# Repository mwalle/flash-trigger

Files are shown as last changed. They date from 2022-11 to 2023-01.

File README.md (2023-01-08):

# Tiny LED Trigger

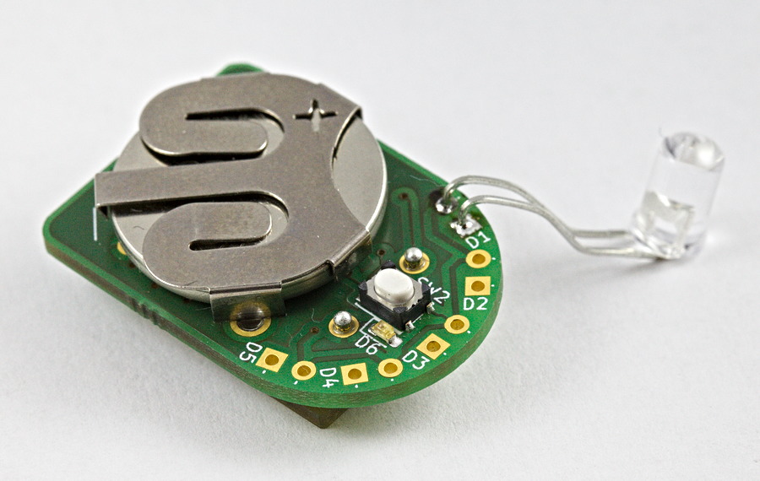
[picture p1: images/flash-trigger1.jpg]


Your simple, cheap and open LED flash trigger for your underwater strobe.

## Features



The flash trigger provides the following features:

- Reliably triggers your optical underwater strobe in manual mode.
- Converts any trigger pulse from your camera to a constant 100µs LED
  pulse.
- Very bright pulse because the LED is driven with a very high current
  (most LEDs have a peak forward current of 100mA-150mA specified for
  100µs for a 1/10 duty cycle).
- Pre-flash supression mode. Useful if your camera has a pre-flash pulse on
  the hot shoe pin.
- Powered by just one CR2032 coin cell.
- More than 10.000 cycles per coin cell.
- Five different positions for the LED.
- Supports up to two LEDs in parallel.
- Battery good indication.
- Extremely small.
- [Open Hardware](https://certification.oshwa.org/de000130.html),
  schematics and layout are free for everyone.

## Pictures

<p>
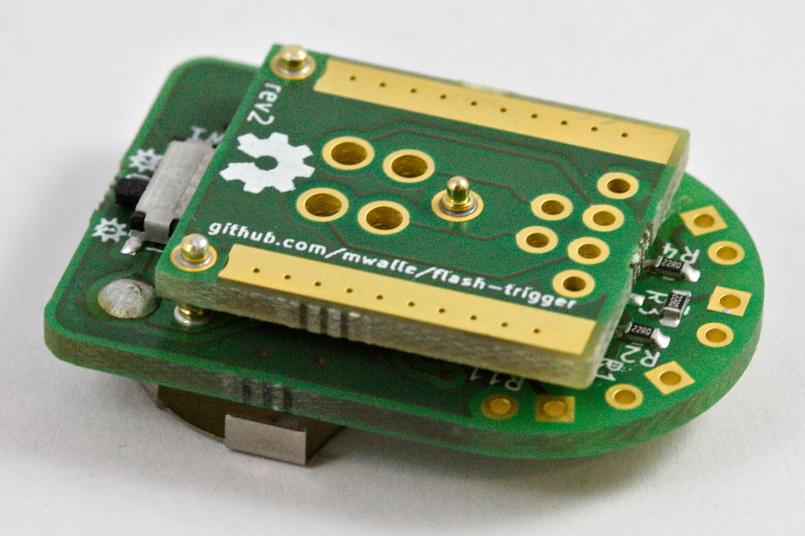
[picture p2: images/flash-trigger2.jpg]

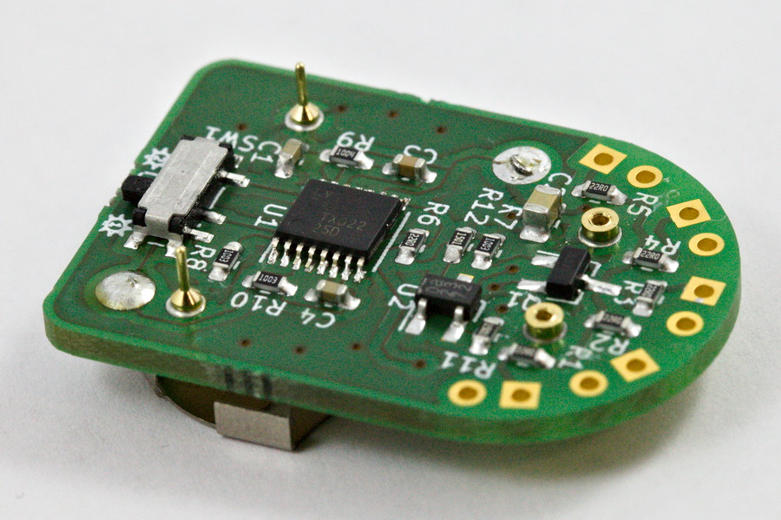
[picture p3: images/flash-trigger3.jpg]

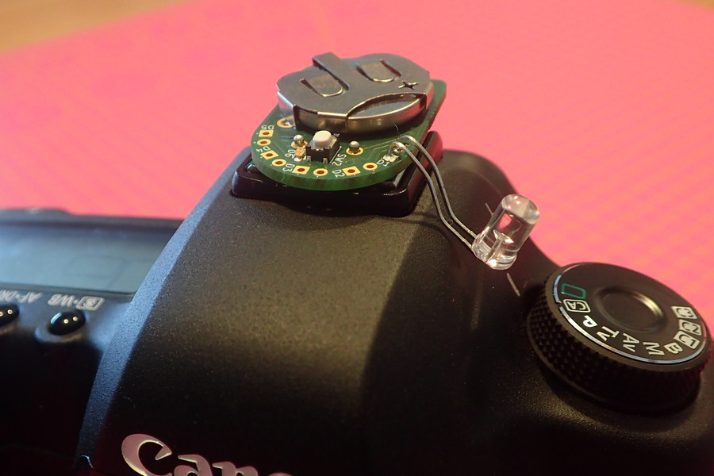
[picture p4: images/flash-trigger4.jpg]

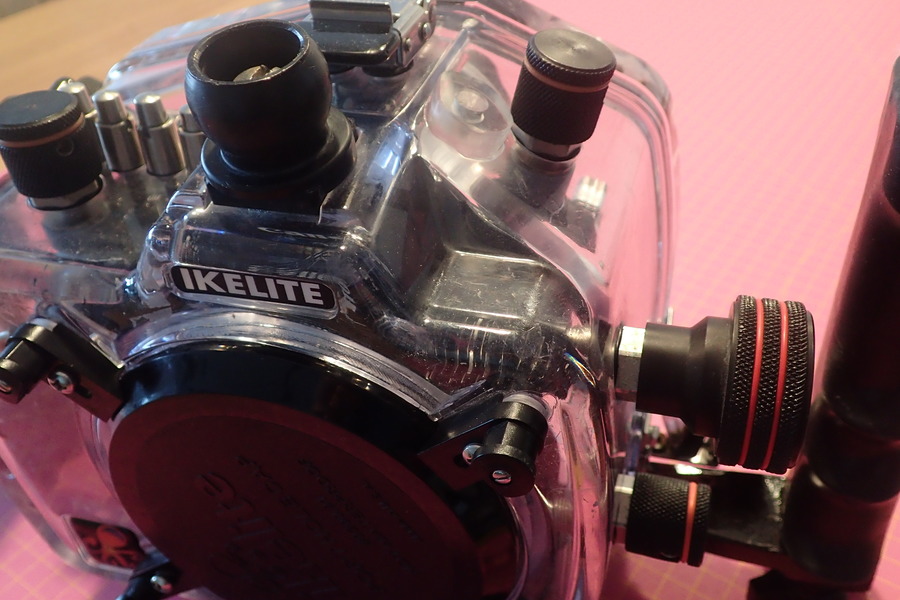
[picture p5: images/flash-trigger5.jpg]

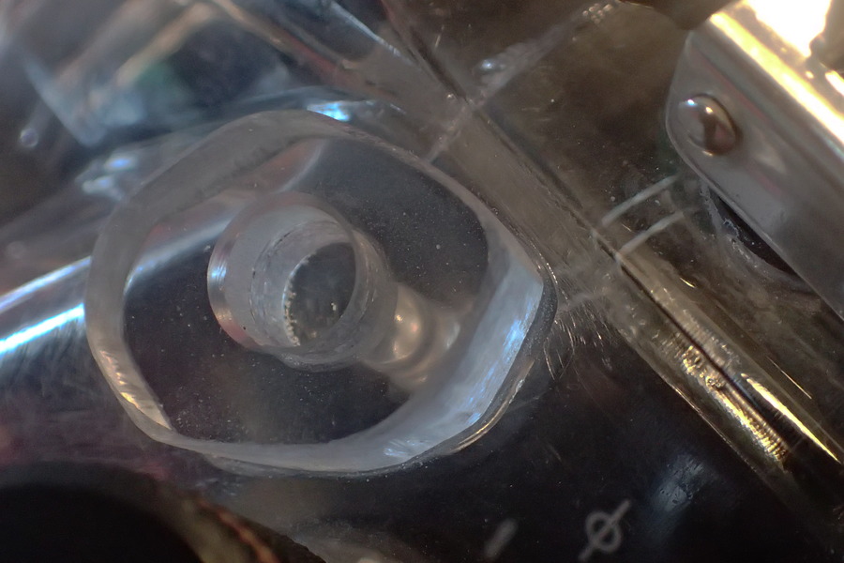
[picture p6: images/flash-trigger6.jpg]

</p>

## Schematics
The LED trigger consists of:
 - the [base board](flash-trigger/flash-trigger.pdf) and
 - a [Canon compatible hot shoe](canon-hotshoe/canon-hotshoe.pdf).

Only populate the X pin of the hot shoe to be compatible with any camera.

## Theory Of Operation

At the heart of the circuit, there is a monostable multivibrator (`U1B`)
which converts any falling edge of the trigger output of your camera to a
constant length pulse of about 100µs. The time constant is given by the
values of `C1` and `R3`. The multivibrator is retriggerable, thus if there
would be a second falling edge within that 100µs pulse the period would
start over. But in practice, this shouldn't matter.

A second monostable multivibrator (`U1A`) can be used to supress a
pre-flash pulse. In this case, the second input of `U1B` is connected to
the output of `U1A` and only if that output is active the 100µs pulse is
generated. The output of `U1A` in turn, will be active for about 100ms
after a *rising* edge of the flash trigger input. Thus the sequence is as
follows:
 1. The camera pulses the trigger output low to generate a pre-flash.
 2. Normally, `U1B` would now trigger a pulse on the falling edge, but
	because the second input is still inactive, no pulse is generated.
 3. On the rising edge (that is, at the end of the pre-flash pulse), `U1A`
	triggers a 100ms pulse and arm `U1B`.
 4. The camera triggers the actual main flash by pulsing the output trigger
	again.
 5. This time, the second input of `U1B` is active and the 100µs trigger
	pulse will be generated.

This has the following two implications:
 * The duration between pre-flash and the main flash must not exceed 100ms.
 * Repeated flashes will be limited to about 10Hz (reciprocal value of the
   100ms)

Both shouldn't really matter. But of course you can tune this time constant
by changing the values of `C3` and `R9`.

The 100µs pulse is enabling the logic level N-channel MOSFET `Q1`, which is
driving the LEDs `D1`..`D5` through individual series resistors `R1`..`R5`.
Depending on the value of the series resistor and the LEDs, it should be
possible to connect up to two LEDs.

The circuit is designed to work down to the forward voltage of the LED.
`U1` will work down to 1.0V. Nevertheless, there is a voltage supervisor,
which is pretty simple: `U2` will pull its output to high if its supply
voltage is greater than 2.7V, thus driving the green LED `D6` with its
series resistor `R11`. At 2.7V the coin cell should still have about 25% of
its capacity, giving the user enough margin.

## Trigger LEDs

The flash trigger has five different LED positions facing left to right.
It should be possible to populate up to two LEDs. The LEDs should be chosen
according to the flash you like to use. The author has successfully tried
red and infrared LEDs with INON flashes. The more the LED is towards the
infrared spectrum, the lower is its forward voltage and the longer it will
work with a given coin cell.

## Bill Of Materials

| Ref | Qty | Part | Footprint |
| --- | --- | --- | --- |
| R1, R2, R3, R4, R5, R6 | 6 | 10Ω Resistor | 0603 |
| R7, R8, R10 | 3 | 100kΩ Resistor | 0603 |
| R9 | 1 | 1MΩ Resistor | 0603 |
| R11, R12 | 2 | 1.5kΩ Resistor | 0603 |
| C1 | 1 | 10nF Ceramic Capacitor | 0603 |
| C2 | 1 | 100µF Ceramic Capacitor | 0805 |
| C3 | 1 | 200nF Ceramic Capacitor | 0603 |
| C4 | 1 | 2.2nF Ceramic Capacitor | 0603 |
| C5 | 1 | 100pF Ceramic Capacitor | 0603 |
| D1, D2, D3, D4, D5 | 5 | LED | THT |
| D6 | 1 | Green LED | 0603 |
| Q1 | 1 | NDS331N N-Channel MOSFET | SOT23-3 |
| U1 | 1 | 74LV123 Dual Retriggerable Monostable Multivibrator | SSOP16 |
| U2 | 1 | BD49K27G Voltage Supervisor 2.7V | SSOP3 |
| SW1 | 1 | PCM12 Switch | - |
| SW2 | 1 | PTS810 Push Button | - |
| BT1 | 1 | CR2032 Coin Cell Holder | - |
| J1, J2 | 2 | MillMax 0550 Pin Receptable | - |
| J3, J4 | 2 | MillMax 0508 PCB Pin | - |

## Kits and PCBs

If you need a PCB, a kit or maybe an assembled board, contact me at
<flash-trigger@walle.cc>.

## License

This source describes Open Hardware and is licensed under the CERN-OHL-S
v2.

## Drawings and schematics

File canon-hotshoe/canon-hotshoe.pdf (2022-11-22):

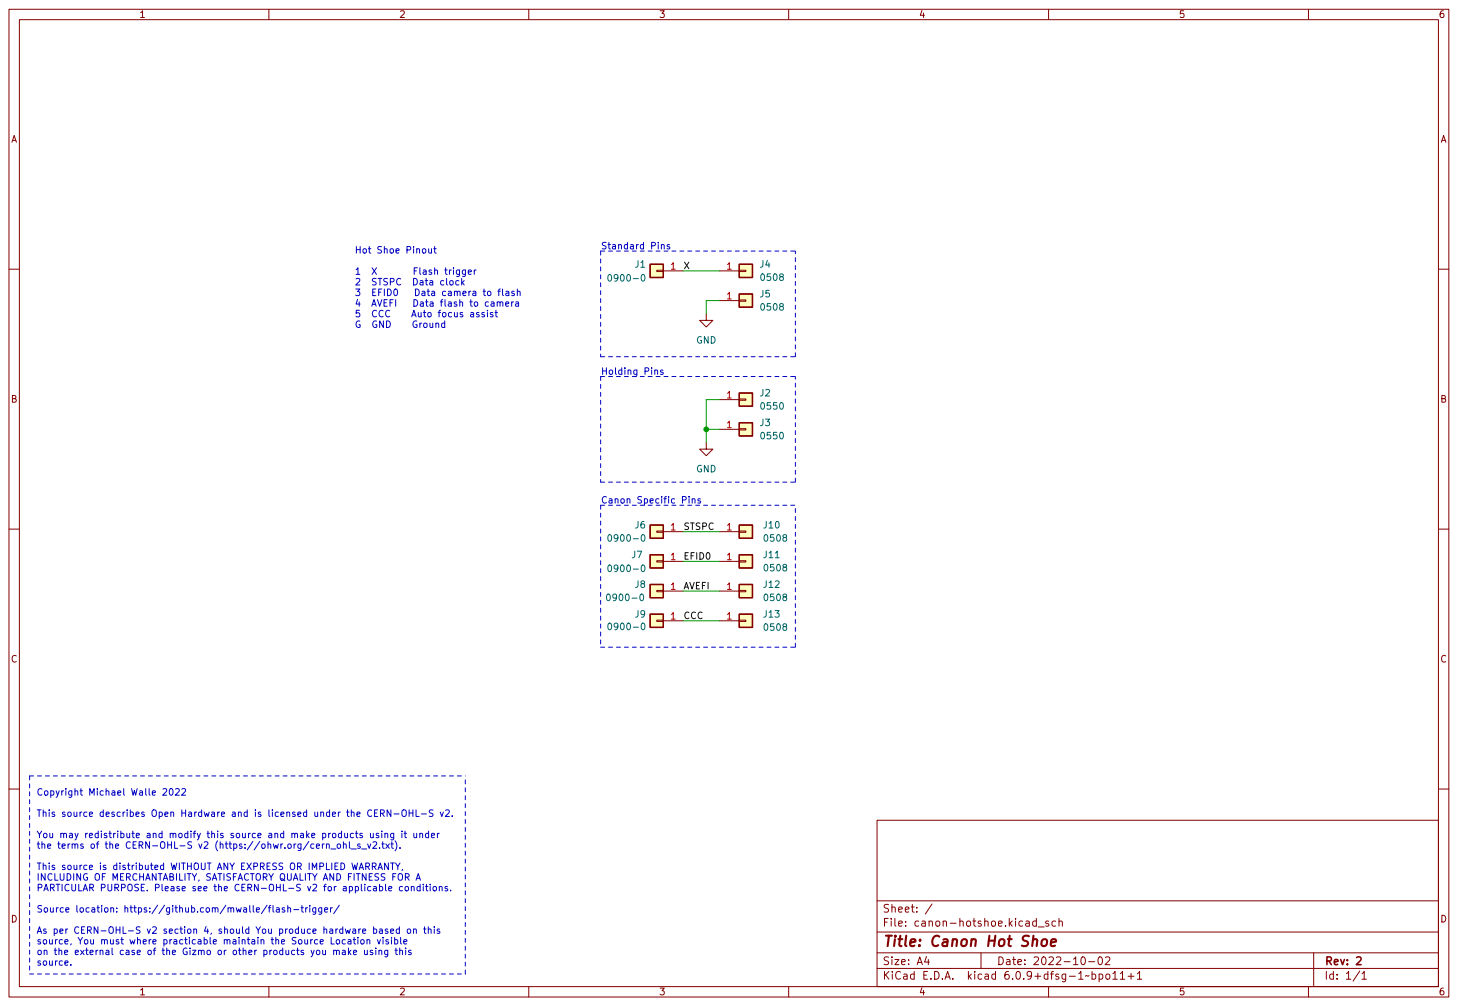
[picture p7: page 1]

4 AVEFI Data flash to camera

This source describes Open Hardware and is licensed under the CERN-OHL-S v2.

You may redistribute and modify this source and make products using it under
the terms of the CERN-OHL-S v2 (https://ohwr.org/cern_ohl_s_v2.txt). This source is distributed WITHOUT ANY EXPRESS OR IMPLIED WARRANTY,

INCLUDING OF MERCHANTABILITY, SATISFACTORY QUALITY AND FITNESS FOR A
PARTICULAR PURPOSE. Please see the CERN-OHL-S v2 for applicable conditions.

File: canon-hotshoe.kicad_sch Sheet: /
Id: 1/1 Title: Canon Hot Shoe

Source location: https://github.com/mwalle/flash-trigger/
As per CERN-OHL-S v2 section 4, should You produce hardware based on this
source, You must where practicable maintain the Source Location visible
on the external case of the Gizmo or other products you make using this
source.

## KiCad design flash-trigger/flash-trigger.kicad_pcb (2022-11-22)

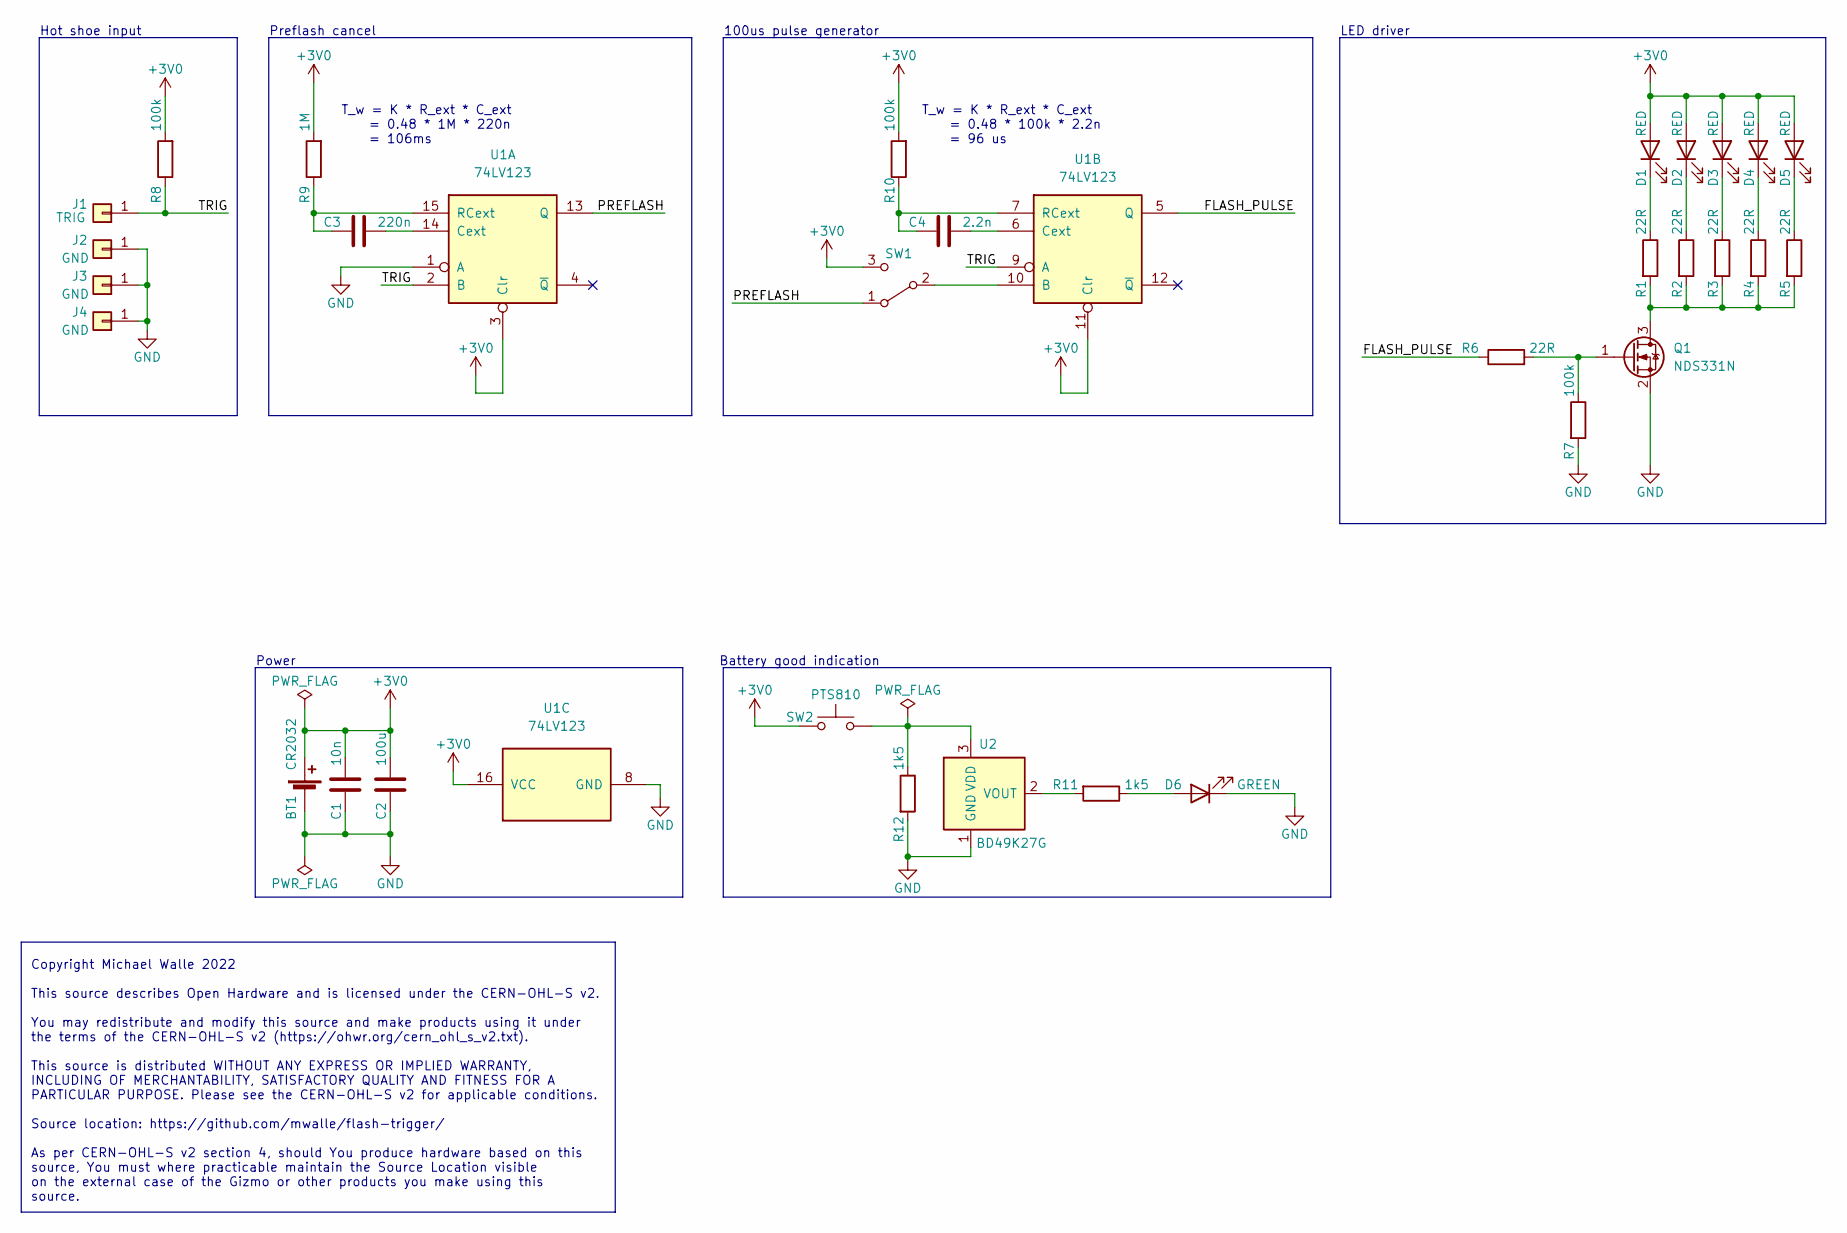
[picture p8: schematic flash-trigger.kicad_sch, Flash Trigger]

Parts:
BT1: CR2032; BatteryHolder_Keystone_2899_1x2032
C1: 10n; C_0603_1608Metric_Pad1.08x0.95mm_HandSolder
C2: 100u; C_0805_2012Metric_Pad1.18x1.45mm_HandSolder
C3: 220n; C_0603_1608Metric_Pad1.08x0.95mm_HandSolder
C4: 2.2n; C_0603_1608Metric_Pad1.08x0.95mm_HandSolder
D1, D2, D3, D4, D5: RED; LED_D5.0mm_Horizontal_O3.81mm_Z3.0mm
D6: GREEN; LED_0603_1608Metric_Pad1.05x0.95mm_HandSolder
J1: TRIG; 0550_52mil
J2: GND; 0550_52mil
J3, J4: GND; 0508_20mil
Q1: NDS331N; SOT-23_Handsoldering
R1, R2, R3, R4, R5, R6: 22R; R_0603_1608Metric_Pad0.98x0.95mm_HandSolder
R7, R8, R10: 100k; R_0603_1608Metric_Pad0.98x0.95mm_HandSolder
R9: 1M; R_0603_1608Metric_Pad0.98x0.95mm_HandSolder
R11, R12: 1k5; R_0603_1608Metric_Pad0.98x0.95mm_HandSolder
SW1: PCM12; SW_SPDT_PCM12
SW2: PTS810; SW_SPST_PTS810
U1: 74LV123; SSOP-16_4.4x5.2mm_P0.65mm
U2: BD49K27G; SOT-23_Handsoldering

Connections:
+3V0: BT1.1 (+), C1.1, C2.1, D1.2 (A), D2.2 (A), D3.2 (A), D4.2 (A), D5.2 (A), R8.2, R9.2, R10.2, SW1.3 (C), SW2.1, U1.3 (Clr), U1.11 (Clr), U1.16 (VCC)
/FLASH_PULSE: R6.1, U1.5 (Q)
/PREFLASH: SW1.1 (A), U1.13 (Q)
/TRIG: J1.1, R8.1, U1.2 (B), U1.9 (A)
GND: BT1.2 (-), C1.2, C2.2, D6.1 (K), J2.1, J3.1, J4.1, Q1.2 (S), R7.2, R12.2, U1.1 (A), U1.8 (GND), U2.1 (GND)
unnamed: C3.1, U1.14 (Cext)
unnamed: C3.2, R9.1, U1.15 (RCext)
unnamed: C4.1, U1.6 (Cext)
unnamed: C4.2, R10.1, U1.7 (RCext)
unnamed: D1.1 (K), R1.1
unnamed: D2.1 (K), R2.1
unnamed: D3.1 (K), R3.1
unnamed: D4.1 (K), R4.1
unnamed: D5.1 (K), R5.1
unnamed: D6.2 (A), R11.1
unnamed: Q1.1 (G), R6.2, R7.1
unnamed: Q1.3 (D), R1.2, R2.2, R3.2, R4.2, R5.2
unnamed: R11.2, U2.2 (VOUT)
unnamed: R12.1, SW2.2, U2.3 (VDD)
unnamed: SW1.2 (B), U1.10 (B)

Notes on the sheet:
100us pulse generator
Battery good indication
T_w = K * R_ext * C_ext = 0.48 * 100k * 2.2n = 96 us
Power
Copyright Michael Walle 2022 This source describes Open Hardware and is licensed under the CERN-OHL-S v2. You may redistribute and modify this source and make products using it under the terms of the CERN-OHL-S v2 (https://ohwr.org/cern_ohl_s_v2.txt). This source is distributed WITHOUT ANY EXPRESS 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
Hot shoe input
LED driver
T_w = K * R_ext * C_ext = 0.48 * 1M * 220n = 106ms
Preflash cancel

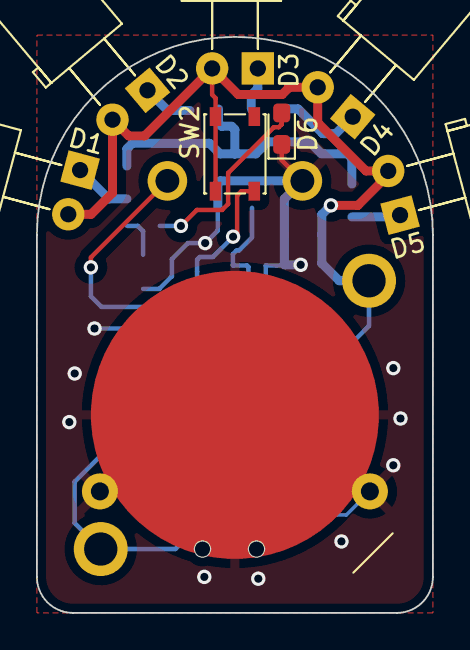
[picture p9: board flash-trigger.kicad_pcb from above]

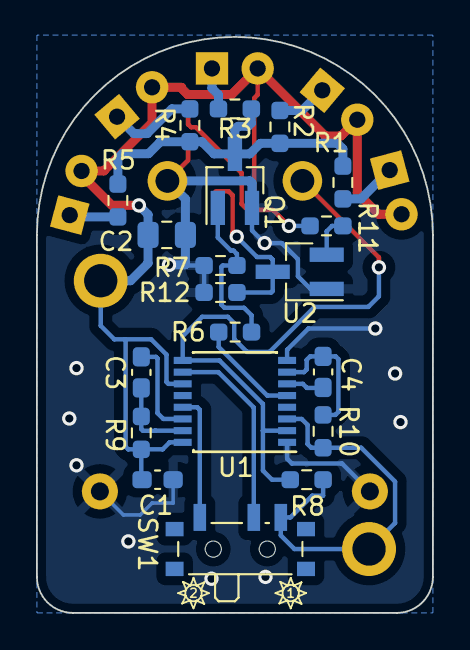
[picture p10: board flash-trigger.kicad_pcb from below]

Board: 2 copper layers, 22.0 x 32.0 mm, 32 parts (24 on the bottom side), 20 nets.

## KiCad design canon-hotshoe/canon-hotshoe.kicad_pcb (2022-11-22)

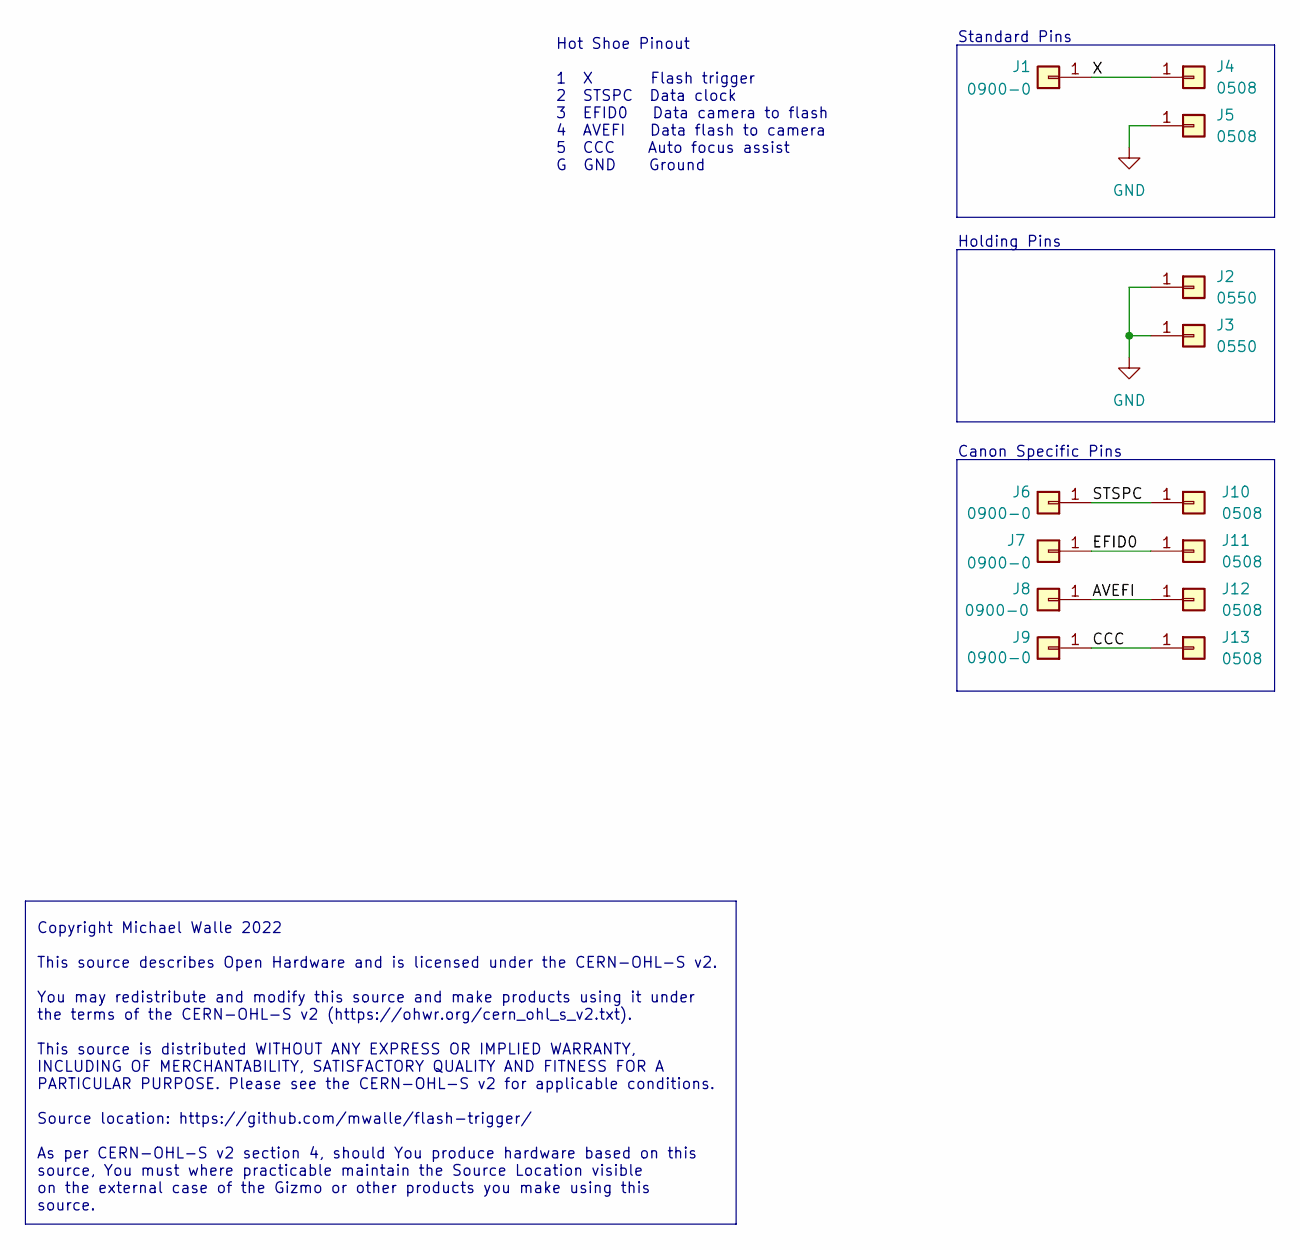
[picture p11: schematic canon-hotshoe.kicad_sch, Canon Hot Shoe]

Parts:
J1, J6, J7, J8, J9: 0900-0; 0900-0_137mil_Reverse
J2, J3: 0550; 0550_52mil
J4, J5, J10, J11, J12, J13: 0508; 0508_20mil

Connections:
/AVEFI: J8.1, J12.1
/CCC: J9.1, J13.1
/EFID0: J7.1, J11.1
/STSPC: J6.1, J10.1
/X: J1.1, J4.1
GND: J2.1, J3.1, J5.1

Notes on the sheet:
Holding Pins
Standard Pins
Hot Shoe Pinout 1 X Flash trigger 2 STSPC Data clock 3 EFID0 Data camera to flash 4 AVEFI Data flash to camera 5 CCC Auto focus assist G GND Ground
Copyright Michael Walle 2022 This source describes Open Hardware and is licensed under the CERN-OHL-S v2. You may redistribute and modify this source and make products using it under the terms of the CERN-OHL-S v2 (https://ohwr.org/cern_ohl_s_v2.txt). This source is distributed WITHOUT ANY EXPRESS 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
Canon Specific Pins

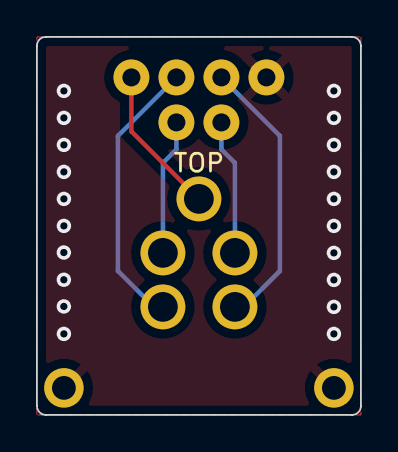
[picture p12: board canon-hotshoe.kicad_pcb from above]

Board: 2 copper layers, 18.0 x 21.0 mm, 13 parts (0 on the bottom side), 6 nets.

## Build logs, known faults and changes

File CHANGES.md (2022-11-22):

# Changes

Format: revX.Y, X denotes a PCB change (and possible BOM change). Y just
denotes a BOM change.

## rev2.1
 - Change C2 to 100uF.
 - Use correct part name for U2.

## rev2.0
 - Fix pre-flash detection.
 - Change from battery bad to battery good detection.
 - Use longer pogo pin.
 - Use two more pins to connect the hot shoe to the flash trigger. Makes
   the PCB stack more stable.
 - Add OSHW logos.

## rev1.0
 - Initial revision

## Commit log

2022-11-22 Fixes and improvements
    * fix the preflash detection
    * clean the canon hot shoe schematics up
    * enlarge the hotshoe pcb and place two new mounting pins
    * change the battery low to a battery good detection
    * move the supervisor ic away from the hot shoe rail
    * use a longer pogo pin
    [canon-hotshoe.kicad_pcb, canon-hotshoe.kicad_sch, flash-trigger.kicad_pcb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]
2022-11-22 flash-trigger: Drop RC circuit and improve layout
    [flash-trigger.kicad_pcb, flash-trigger.kicad_sch]
2022-11-22 Renumber RefDes and add OSHW logo and URL
    [canon-hotshoe.kicad_pcb, flash-trigger.kicad_pcb, flash-trigger.kicad_sch]
2022-11-22 flash-trigger: replace BD49KxxG with BD49K27G
    We use a 2.7V voltage supervisor.
    [flash-trigger.kicad_pcb, flash-trigger.kicad_sch]
2022-11-22 canon-hotshoe: exclude OSHW symbol from schematics
    [canon-hotshoe.kicad_pcb]
2022-11-22 schematics: Fix the battery good title
    Since rev2 this is now a battery good detection.
    [flash-trigger.kicad_sch]
2022-11-22 flash-trigger: Increase C2 to 100uF
    [flash-trigger.kicad_pcb, flash-trigger.kicad_sch]
2022-11-22 flash-trigger: Update value of SW2
    Reflect the actual component value instead of its function.
    [flash-trigger.kicad_pcb, flash-trigger.kicad_sch]
